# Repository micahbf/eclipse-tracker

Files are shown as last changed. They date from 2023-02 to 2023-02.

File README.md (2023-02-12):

This repo contains everything needed to make an Eclipse turn tracker.

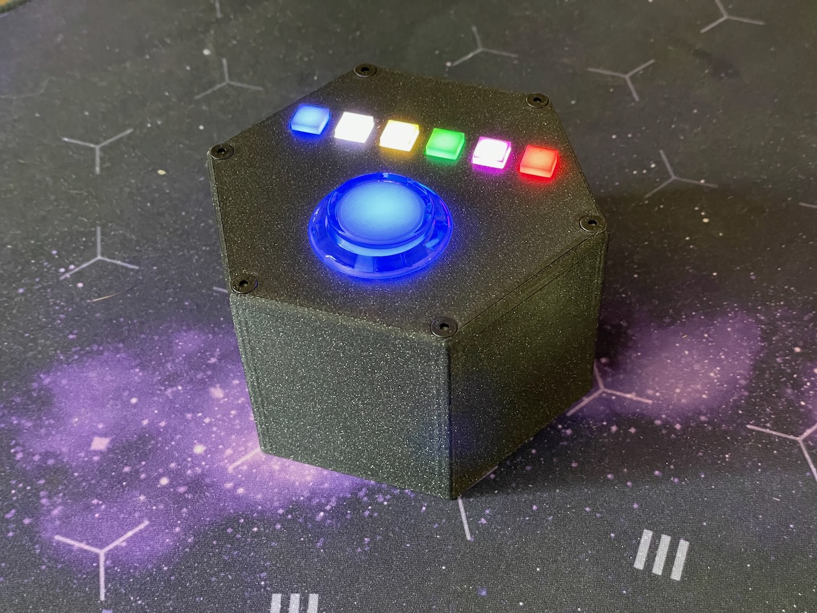
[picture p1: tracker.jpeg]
Eclipse turn tracker


## Operation

The tracker has a few modes, from startup:

1. Select number of players

- hit the arcade button to change the number of players, then double tap to confirm

2. Random draft

- Species are drafted randomly. Each player hits the button to get assigned their species
- Pressing the undo button goes back to re-draft the player who last drafted
- After all players have drafted, play order is shuffled

3. Turn tracking

- The play order is displayed on the row of lights
- The current player is shown by the button light
- When the current player is done with their turn, they hit the button and it advances to the next plyaer
- If the current player passes, they double-tap the arcade button. Their turn order light is dimmed and they are removed from the play order.
- After all players pass, the pass order is used to set the new play order and all players are reset
- The undo button reverts whatever the last button press did

There is also a battery check mode, which I use when charging the tracker. This is partially because I wired
the tracker in such a way that I can't charge the battery unless it's turned on. (The battery itself is directly
switched.)

Pressing the undo button 3 times quickly will toggle battery check mode. In this mode, one light will remain on
to show the voltage (and charge state) state of the battery:

- Green >4.0V
- Yellow 3.6V - 4.0V
- Orange 3.4V - 3.6V
- Red <3.4V

Pressing the undo button 3 times again will return to the previous mode.

## This Repo

The [tracker.ino](/tracker/tracker.ino) file is an Arduino sketch. I used an ATmega 328P based Arduino, specifically an Adafruit Feather 328P.

Also included is the source Fusion 360 file for the enclosure, and individual 3MF files for the three parts. The parts are:

- Main body
- Lid
- Indicators

The main body and lid are pretty straightforward - I printed them with PLA using 0.2mm layer height.

The indicators need to be printed in 2 colors - an opaque color for the bottom where the NeoPixels are mounted,
and a translucent color for the indicators themselves.

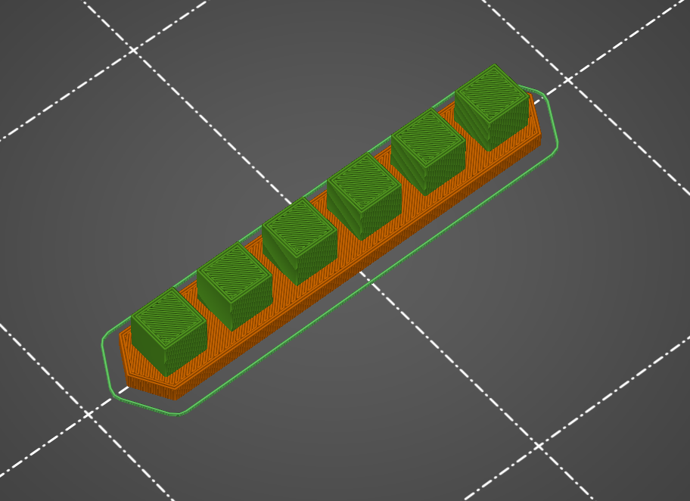
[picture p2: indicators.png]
Detail of the indicator slicing


## Parts

Parts used were:

- [Adafruit Feather 328P](https://www.adafruit.com/product/3458)
- 7 x [Adafruit NeoPixel Mini Button](https://www.adafruit.com/product/1612)
- [Arcade Button - 30mm Translucent Clear](https://www.adafruit.com/product/471)
  - This was modified to contain a NeoPixel per [this guide](https://learn.adafruit.com/neopixel-arcade-button)
- [16mm Panel Mount Momentary Pushbutton - Red](https://www.adafruit.com/product/1445)
- [Lithium Ion Polymer Battery - 3.7v 2500mAh](https://www.adafruit.com/product/328)
- [SW-R3-1A-A-1-0 Subminiature Rocker Switch](https://www.digikey.com/short/hp38423t)
- [680uF electrolytic capacitor](https://www.digikey.com/short/7tjn93td)
- 4 x M2x5 self-tapping screws to mount the Feather
- 6 x M3x8 countersunk screws to attach the top
- 6 x M3 threaded inserts

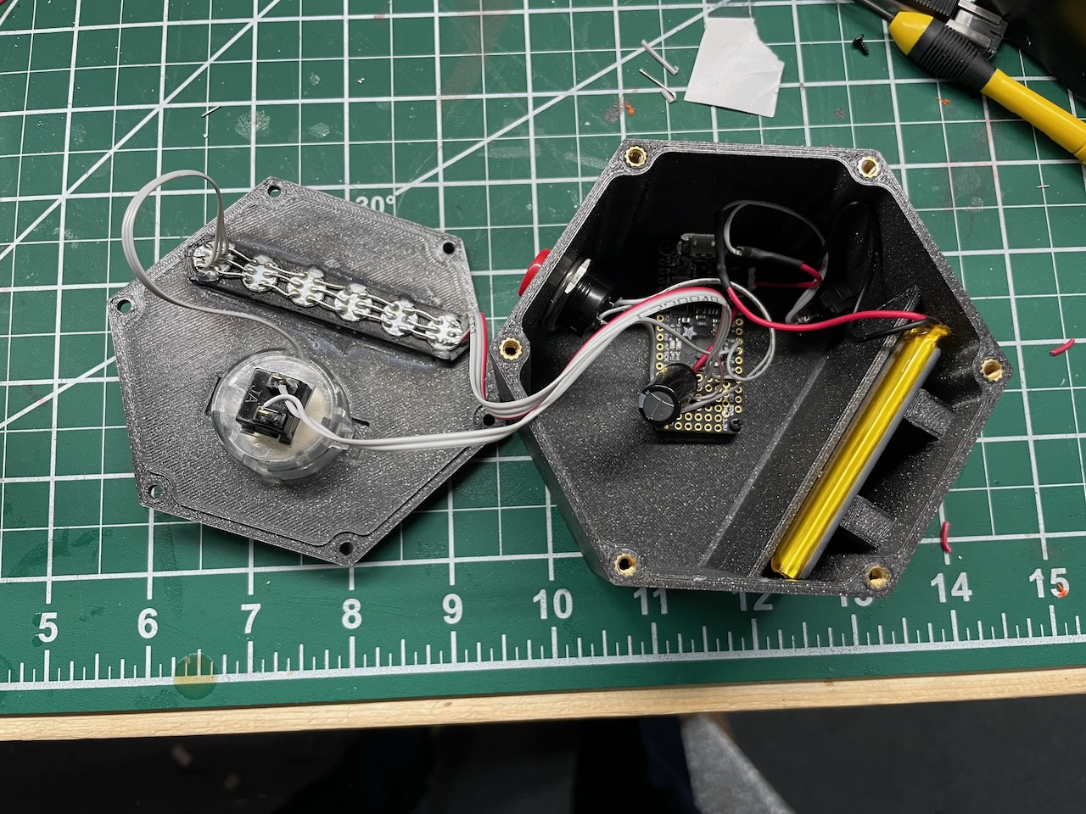
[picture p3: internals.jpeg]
Tracker internals


## Oh hi

I might get around to documenting more, but until then, get in touch with me if you have any questions!
micah@xlmpq.com

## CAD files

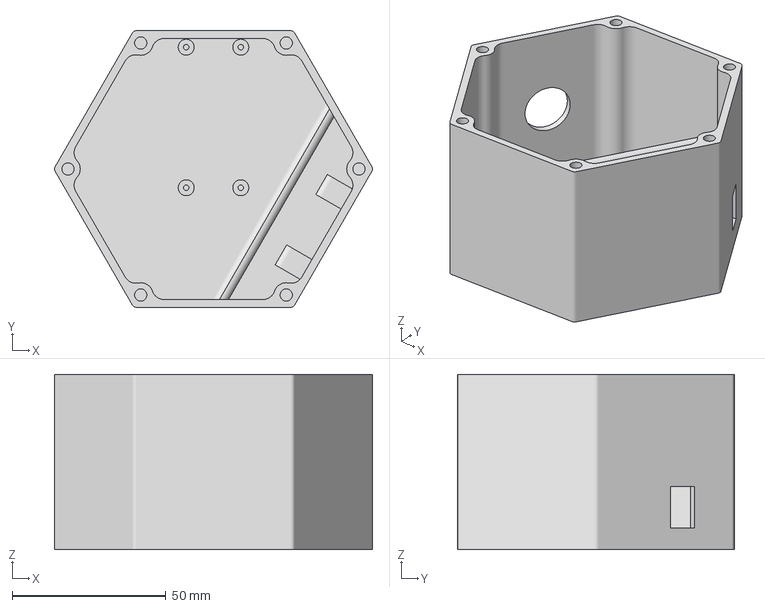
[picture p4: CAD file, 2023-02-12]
main_body.3mf
103.5 x 90.0 x 57.0 mm

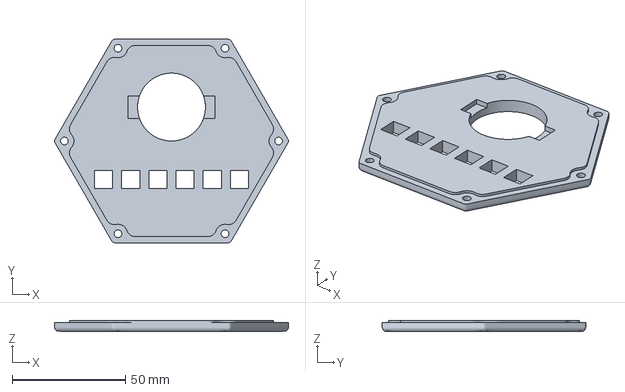
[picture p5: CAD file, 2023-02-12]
lid.3mf
103.5 x 90.0 x 5.00 mm

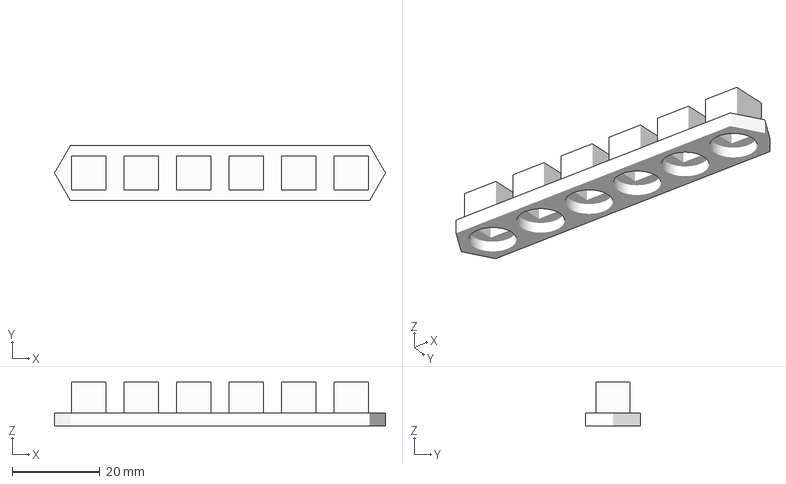
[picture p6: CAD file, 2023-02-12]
indicators.3mf
75.7 x 12.6 x 10.0 mm

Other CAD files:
eclipse 2 v21.f3z

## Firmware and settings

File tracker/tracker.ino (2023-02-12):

#include <FastLED.h>
#include <EasyButton.h>

#define NEOPIXEL_PIN 6
#define NEOPIXEL_COUNT 7
#define NP_MAIN_BUTTON 6
#define NP_PLAYER_START 0

// brightness levels are 0-255
#define BUTTON_BRIGHTNESS 192
#define PLAYER_BRIGHTNESS 128
#define PASSED_BRIGHTNESS 32

#define MAIN_BUTTON_PIN 2
#define UNDO_BUTTON_PIN 3
#define DBL_PRESS_DEBOUNCE 250

#define RANDOM_SEED_PIN A0
#define VBATPIN A6

enum TrackerMode { numPlayerSelect,
                   randomColorAssign,
                   turnTracker,
                   batteryMonitor };

struct TurnState {
  byte prevPlayer;
  byte activePlayer;
  int playIndex;
  byte playOrder[6];
  int numPassed;
  byte passOrder[6];

  TurnState() {
    prevPlayer = 0;
    activePlayer = 0;
    playIndex = 0;
    numPassed = 0;
  }
};

#define TURN_HISTORY_LENGTH 20
struct {
  TurnState history[TURN_HISTORY_LENGTH];
  int currentState;
  int historyLength = 0;
} turnHistory;

CRGB leds[NEOPIXEL_COUNT];

EasyButton mainButton(MAIN_BUTTON_PIN);
EasyButton undoButton(UNDO_BUTTON_PIN);

const CRGB playerColors[] = { CRGB::Blue, CRGB::Red, CRGB::Green, CRGB::White, CRGB::Yellow, CRGB::Purple };

int numPlayers = 4;
TrackerMode currTrackerMode = numPlayerSelect;

unsigned long lastButtonPress = 0;
unsigned long lastTick = 0;

void setup() {
  // Serial.begin(9600);
  randomSeed(analogRead(RANDOM_SEED_PIN));
  FastLED.addLeds<NEOPIXEL, NEOPIXEL_PIN>(leds, NEOPIXEL_COUNT).setCorrection(TypicalLEDStrip);
  showBlank();
  mainButton.begin();
  mainButton.onPressed(handleMainSinglePress);
  mainButton.onSequence(2, DBL_PRESS_DEBOUNCE, handleMainDoublePress);
  undoButton.begin();
  undoButton.onPressed(handleUndoSinglePress);
  undoButton.onSequence(3, DBL_PRESS_DEBOUNCE, toggleBatteryMonitor);

  initTurnHistory();

  showNumPlayerSelect();
}

// void debugCurrState() {
//   TurnState &currState = getCurrentState();

//   Serial.print("\n\n");
//   Serial.print(int(&currState), HEX);
//   Serial.print("\nprevPlayer ");
//   Serial.print(currState.prevPlayer, DEC);
//   Serial.print("\nactivePlayer ");
//   Serial.print(currState.activePlayer, DEC);
//   Serial.print("\nplayIndex ");
//   Serial.print(currState.playIndex, DEC);
//   Serial.print("\nnumPassed ");
//   Serial.print(currState.numPassed, DEC);
//   Serial.print("\npassOrder ");
//   for(int i = 0; i < 6; i++) {
//     Serial.print(currState.passOrder[i], DEC);
//     Serial.print(" ");
//   }
// }

void handleMainSinglePress() {
  unsigned long now = millis();
  if (now - lastButtonPress < 250) {
    lastButtonPress = now;
    return;
  }

  lastButtonPress = now;

  switch (currTrackerMode) {
    case turnTracker:
      nextPlayer();
      break;
    case numPlayerSelect:
      incNumPlayers();
      break;
    case randomColorAssign:
      assignColor();
      break;
  }
}

void handleMainDoublePress() {
  switch (currTrackerMode) {
    case turnTracker:
      passPrevPlayer();
      break;
    case numPlayerSelect:
      numPlayersConfirm();
      break;
  }
}

void handleUndoSinglePress() {
  switch (currTrackerMode) {
    case turnTracker:
      trackerUndo();
      break;
    case randomColorAssign:
      undoAssign();
      break;
  }
}

void toggleBatteryMonitor() {
  static TrackerMode lastTrackerMode;

  if (currTrackerMode == batteryMonitor) {
    currTrackerMode = lastTrackerMode;
    lastTrackerMode = batteryMonitor;
  } else {
    lastTrackerMode = currTrackerMode;
    currTrackerMode = batteryMonitor;
  }
  showBlank();
  showCurrentMode();
}

void showBlank() {
  for (int led = 0; led < NEOPIXEL_COUNT; led++) {
    leds[led] = CRGB::Black;
  }
  FastLED.show();
}

void showNumPlayerSelect() {
  leds[NP_MAIN_BUTTON] = CRGB::Plum;
  leds[NP_MAIN_BUTTON].nscale8(BUTTON_BRIGHTNESS);

  for (int i = 0; i < 6; i++) {
    int led = i + NP_PLAYER_START;
    if (i < numPlayers) {
      leds[led] = CRGB::Plum;
      leds[led].nscale8(PLAYER_BRIGHTNESS);
    } else {
      leds[led] = CRGB::Black;
    }
  }
  FastLED.show();
}

void showColorAssign() {
  TurnState &turnState = getCurrentState();

  leds[NP_MAIN_BUTTON] = playerColors[turnState.activePlayer];
  leds[NP_MAIN_BUTTON].nscale8(BUTTON_BRIGHTNESS);

  for (int i = 0; i < numPlayers; i++) {
    int led = i + NP_PLAYER_START;
    if (i <= turnState.activePlayer) {
      leds[led] = playerColors[i];
      leds[led].nscale8(PLAYER_BRIGHTNESS);
    } else {
      leds[led] = CRGB::Black;
    }
  }
}

void showTurnTracker() {
  TurnState &turnState = getCurrentState();

  leds[NP_MAIN_BUTTON] = playerColors[turnState.activePlayer];
  leds[NP_MAIN_BUTTON].nscale8(BUTTON_BRIGHTNESS);

  for (int i = 0; i < numPlayers; i++) {
    int led = i + NP_PLAYER_START;
    byte player = turnState.playOrder[i];
    leds[led] = playerColors[player];

    if (isPlayerPassed(turnState, player)) {
      leds[led].nscale8(PASSED_BRIGHTNESS);
    } else {
      leds[led].nscale8(PLAYER_BRIGHTNESS);
    }
  }

  FastLED.show();
}

void showBatteryMonitor() {
  float vbat = analogRead(VBATPIN);
  vbat *= 2;     // voltage divided by 2, so multiply back
  vbat *= 3.3;   // Multiply by 3.3V, our reference voltage
  vbat /= 1024;  // convert to voltage

  showBlank();
  if (vbat > 4.0) {
    leds[NP_PLAYER_START + 5] = CRGB::Green;
  } else if (vbat > 3.6) {
    leds[NP_PLAYER_START + 5] = CRGB::Yellow;
  } else if (vbat > 3.4) {
    leds[NP_PLAYER_START + 5] = CRGB::DarkOrange;
  } else {
    leds[NP_PLAYER_START + 5] = CRGB::Crimson;
  }
  leds[NP_PLAYER_START + 5].nscale8(64);

  FastLED.show();
}

void showCurrentMode() {
  switch (currTrackerMode) {
    case numPlayerSelect:
      showNumPlayerSelect();
      break;
    case randomColorAssign:
      showColorAssign();
      break;
    case turnTracker:
      showTurnTracker();
      break;
    case batteryMonitor:
      showBatteryMonitor();
      break;
  }
}

void blinkTurnTracker() {
  for (int i = 0; i < 8; i++) {
    showBlank();
    delay(75);
    showTurnTracker();
    delay(175);
  }
}

void incNumPlayers() {
  if (numPlayers == 6) {
    numPlayers = 2;
  } else {
    numPlayers++;
  }

  showNumPlayerSelect();
}

void numPlayersConfirm() {
  // undo the single last button press
  if (numPlayers == 2) {
    numPlayers = 6;
  } else {
    numPlayers--;
  }

  currTrackerMode = randomColorAssign;
  showBlank();
  showColorAssign();
}

void randomAssignTick() {
  TurnState &turnState = getCurrentState();
  byte nextColor = turnState.playOrder[turnState.playIndex];
  bool colorTaken;
  do {
    colorTaken = false;
    nextColor = nextColor == 5 ? 0 : nextColor + 1;

    for (int i = 0; i < turnState.playIndex; i++) {
      if (turnState.playOrder[i] == nextColor) {
        colorTaken = true;
      }
    }
  } while (colorTaken);

  turnState.playOrder[turnState.playIndex] = nextColor;
  leds[NP_MAIN_BUTTON] = playerColors[nextColor];
  leds[NP_MAIN_BUTTON].nscale8(BUTTON_BRIGHTNESS);
  leds[NP_PLAYER_START + turnState.playIndex] = playerColors[nextColor];
  leds[NP_PLAYER_START + turnState.playIndex].nscale8(PLAYER_BRIGHTNESS);
  FastLED.show();
}

void shufflePlayOrder() {
  TurnState &turnState = getCurrentState();

  for (int n = 0; n < 30; n++) {
    for (int i = 0; i < numPlayers; i++) {
      int n = random(0, numPlayers);
      int temp = turnState.playOrder[n];
      turnState.playOrder[n] = turnState.playOrder[i];
      turnState.playOrder[i] = temp;
    }
    turnState.activePlayer = turnState.playOrder[0];
    showTurnTracker();
    delay(150);
  }
}

void assignColor() {
  TurnState &turnState = getCurrentState();
  if (turnState.playIndex != 5) {
    delay(2000);
  }

  if (turnState.playIndex == numPlayers - 1) {
    currTrackerMode = turnTracker;
    turnState.playIndex = 0;
    showBlank();
    shufflePlayOrder();
    blinkTurnTracker();
    showTurnTracker();
  } else {
    turnState.playIndex++;
  }
}

void undoAssign() {
  TurnState &turnState = getCurrentState();
  leds[NP_PLAYER_START + turnState.playIndex] = CRGB::Black;
  turnState.playIndex--;
}

void nextPlayer() {
  TurnState &newState = advanceTurnState();
  newState.prevPlayer = newState.activePlayer;

  do {
    newState.playIndex = (newState.playIndex + 1) % numPlayers;
    newState.activePlayer = newState.playOrder[newState.playIndex];
  } while (isPlayerPassed(newState, newState.activePlayer));

  // debugCurrState();
  showTurnTracker();
}

void passPrevPlayer() {
  TurnState &newState = advanceTurnState();
  newState.passOrder[newState.numPassed] = newState.prevPlayer;
  newState.numPassed++;


  if (newState.numPassed == numPlayers) {
    for (int i = 0; i < numPlayers; i++) {
      newState.playOrder[i] = newState.passOrder[i];
    }
    newState.playIndex = 0;
    newState.prevPlayer = newState.activePlayer;
    newState.activePlayer = newState.playOrder[0];
    newState.numPassed = 0;
  }

  // debugCurrState();
  showTurnTracker();
}

bool isPlayerPassed(TurnState &turnState, byte player) {
  if (turnState.numPassed == 0) {
    return false;
  }

  for (int i = 0; i < turnState.numPassed; i++) {
    if (turnState.passOrder[i] == player) {
      return true;
    }
  }

  return false;
}

void trackerUndo() {
  if (turnHistory.historyLength == 0) {
    return;
  }

  int newState;
  if (turnHistory.currentState - 1 < 0) {
    newState = TURN_HISTORY_LENGTH - 1;
  } else {
    newState = turnHistory.currentState - 1;
  }

  turnHistory.currentState = newState;
  turnHistory.historyLength--;
  showTurnTracker();
}

TurnState &getCurrentState() {
  return turnHistory.history[turnHistory.currentState];
}

TurnState &advanceTurnState() {
  int nextStateIdx = (turnHistory.currentState + 1) % TURN_HISTORY_LENGTH;
  turnHistory.history[nextStateIdx] = turnHistory.history[turnHistory.currentState];
  turnHistory.currentState = nextStateIdx;
  if (turnHistory.historyLength < TURN_HISTORY_LENGTH) {
    turnHistory.historyLength++;
  }

  TurnState &nextState = turnHistory.history[nextStateIdx];
  return nextState;
}

void initTurnHistory() {
  for (int i = 0; i < TURN_HISTORY_LENGTH; i++) {
    turnHistory.history[i] = TurnState();
  }
  turnHistory.currentState = 0;

  for (int i = 0; i < numPlayers; i++) {
    turnHistory.history[0].playOrder[i] = byte(i);
  }
}

void loop() {
  mainButton.read();
  undoButton.read();

  unsigned long now = millis();
  if (currTrackerMode == randomColorAssign && now != lastTick && now % 50 == 0) {
    randomAssignTick();
  }
  if (currTrackerMode == batteryMonitor && now != lastTick && now % 1000 == 0) {
    showBatteryMonitor();
  }
  lastTick = now;
}

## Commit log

2023-01-07 Start arduino work
2023-02-11 Add Fusion 360 file
    [eclipse 2 v21.f3z]
2023-02-12 Add battery monitor mode
2023-02-12 Add 3MF files
    [indicators.3mf, lid.3mf, main_body.3mf]
2023-02-12 Document battery check mode
2023-02-12 Add smoothing capacitor to parts list
